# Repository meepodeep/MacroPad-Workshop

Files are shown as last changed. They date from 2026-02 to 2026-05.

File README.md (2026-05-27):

# MacroPad-Workshop
macro pad design for the CFMG workshop
# ASSEMBLY STEPS

1. bend the legs of the diodes and put them into the holes labeled d(x) on the back of the pcb (the side with the logo). make sure the black stripe on the diode is pointing to the square hole
2. solder them in from the side where they are sticking out
3. cut the legs off the diodes
4. click the switches into the plate with the pins facing up
5. solder the pin headers that were included with the microcontroller on the back side of the board (side with logo), the short side of the headers go through the pcb.
6. click the switches and plate onto the board and then solder the switches.
7. solder the microcontroller onto the pin headers one pin above the bottom, this is due to an error in the library i used.

# FLASHING STEPS

1. install qmk toolbox
2. install the cmfg_macropad_default.hex file from this repo
3. select it in qmk toolbox
4. select auto flash
5. connect the macropad to your computer and then short the reset and ground pins using some metal thing

# BOM

|Item |Price|Quantity|Use |Link |
|---|-----|---|---|---|
|Switches |5.81 |30pcs |switches |https://www.aliexpress.us/item/3256811859979458.html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 |
|Pro micro |4.38 |1 |runs the macropad|https://www.aliexpress.us/item/2251801390587459.html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 |
|1N4148 Diode|2.68 |1 |is diode |https://www.aliexpress.us/item/3256804886900665.html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|
|Keycaps |4.07 |1 |is keycap |https://www.aliexpress.us/item/3256808845306164.html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 |

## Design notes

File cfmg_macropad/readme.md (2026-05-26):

# cfmg_macropad

cfmg_macropad

*A short description of the keyboard/project*

* Keyboard Maintainer: [meepodeep](https://github.com/meepodeep)
* Hardware Supported: *The PCBs, controllers supported*
* Hardware Availability: *Links to where you can find this hardware*

Make example for this keyboard (after setting up your build environment):

    make cfmg_macropad:default

Flashing example for this keyboard:

    make cfmg_macropad:default:flash

See the [build environment setup](https://docs.qmk.fm/#/getting_started_build_tools) and the [make instructions](https://docs.qmk.fm/#/getting_started_make_guide) for more information. Brand new to QMK? Start with our [Complete Newbs Guide](https://docs.qmk.fm/#/newbs).

## Bootloader

Enter the bootloader in 3 ways:

* **Bootmagic reset**: Hold down the key at (0,0) in the matrix (usually the top left key or Escape) and plug in the keyboard
* **Physical reset button**: Briefly press the button on the back of the PCB - some may have pads you must short instead
* **Keycode in layout**: Press the key mapped to `QK_BOOT` if it is available

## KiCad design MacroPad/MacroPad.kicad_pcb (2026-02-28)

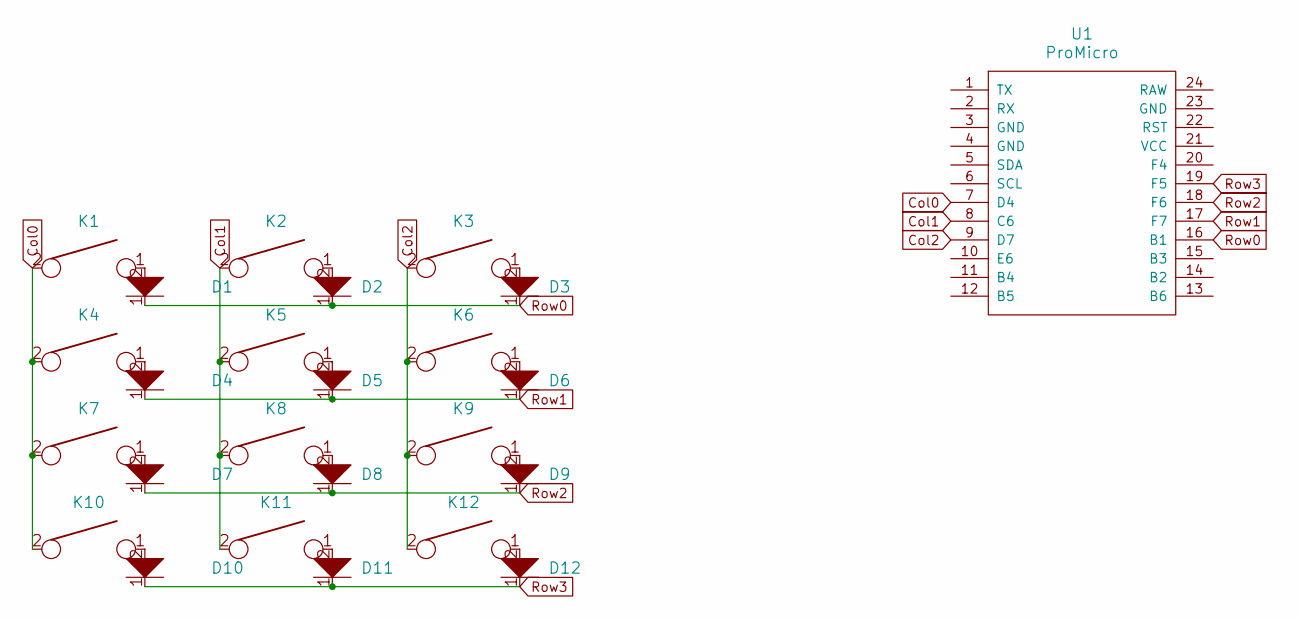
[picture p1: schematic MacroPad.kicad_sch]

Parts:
D1, D2, D3, D4, D5, D6, D7, D8, D9, D10, D11, D12: D; D_SOD123_axial
K1, K2, K3, K4, K5, K6, K7, K8, K9, K10, K11, K12: KEYSW; Mx_Alps_100
U1: ProMicro; Pro_Micro

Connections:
Col0: K1.2, K4.2, K7.2, K10.2, U1.7 (D4)
Col1: K2.2, K5.2, K8.2, K11.2, U1.8 (C6)
Col2: K3.2, K6.2, K9.2, K12.2, U1.9 (D7)
unnamed: D1.2, K1.1
unnamed: D2.2, K2.1
unnamed: D3.2, K3.1
unnamed: D4.2, K4.1
unnamed: D5.2, K5.1
unnamed: D6.2, K6.1
unnamed: D7.2, K7.1
unnamed: D8.2, K8.1
unnamed: D9.2, K9.1
unnamed: D10.2, K10.1
unnamed: D11.2, K11.1
unnamed: D12.2, K12.1
Row0: D1.1, D2.1, D3.1, U1.16 (B1)
Row1: D4.1, D5.1, D6.1, U1.17 (F7)
Row2: D7.1, D8.1, D9.1, U1.18 (F6)
Row3: D10.1, D11.1, D12.1, U1.19 (F5)

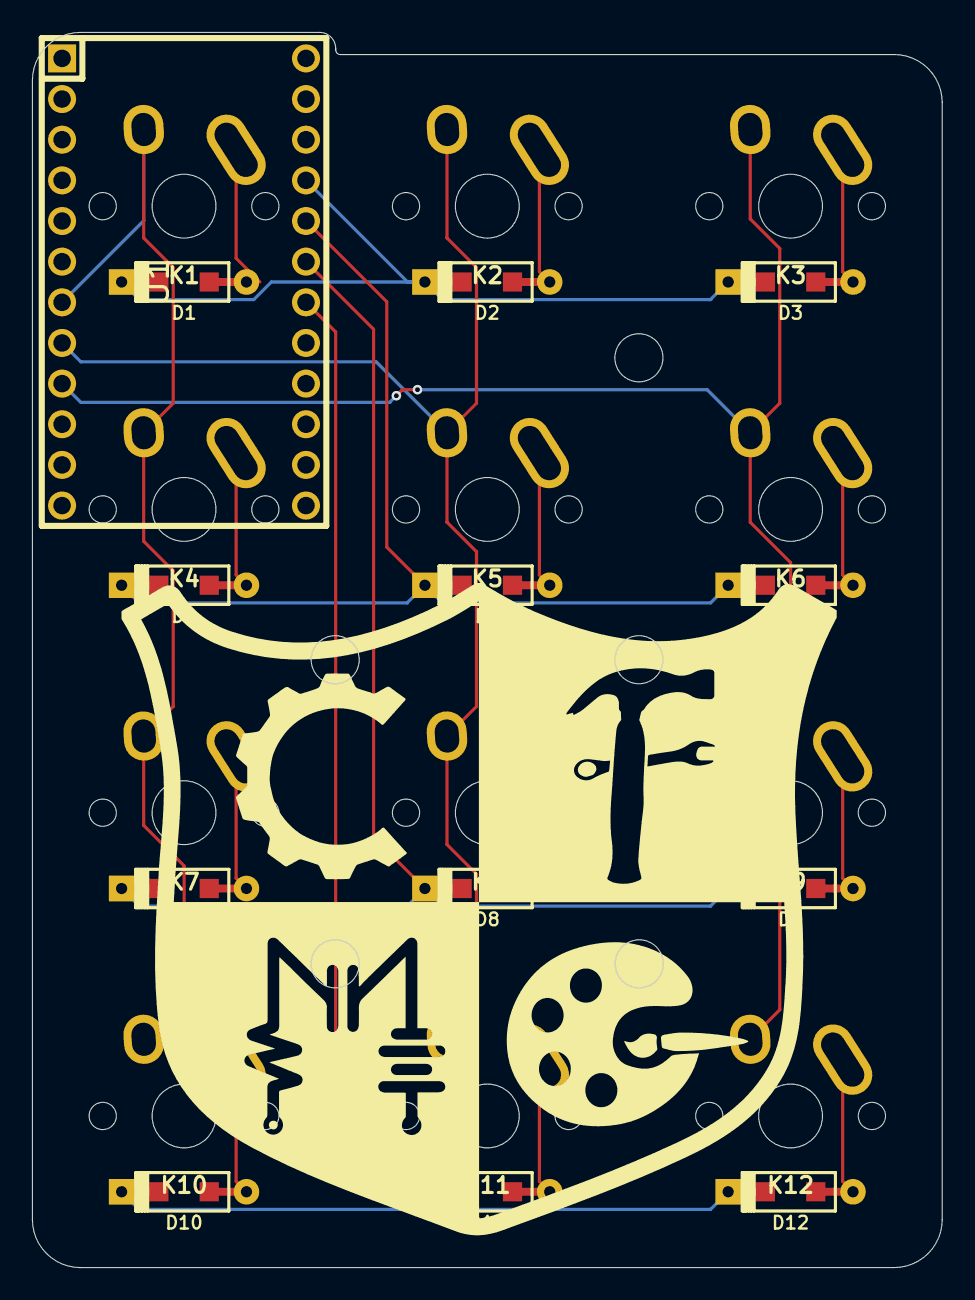
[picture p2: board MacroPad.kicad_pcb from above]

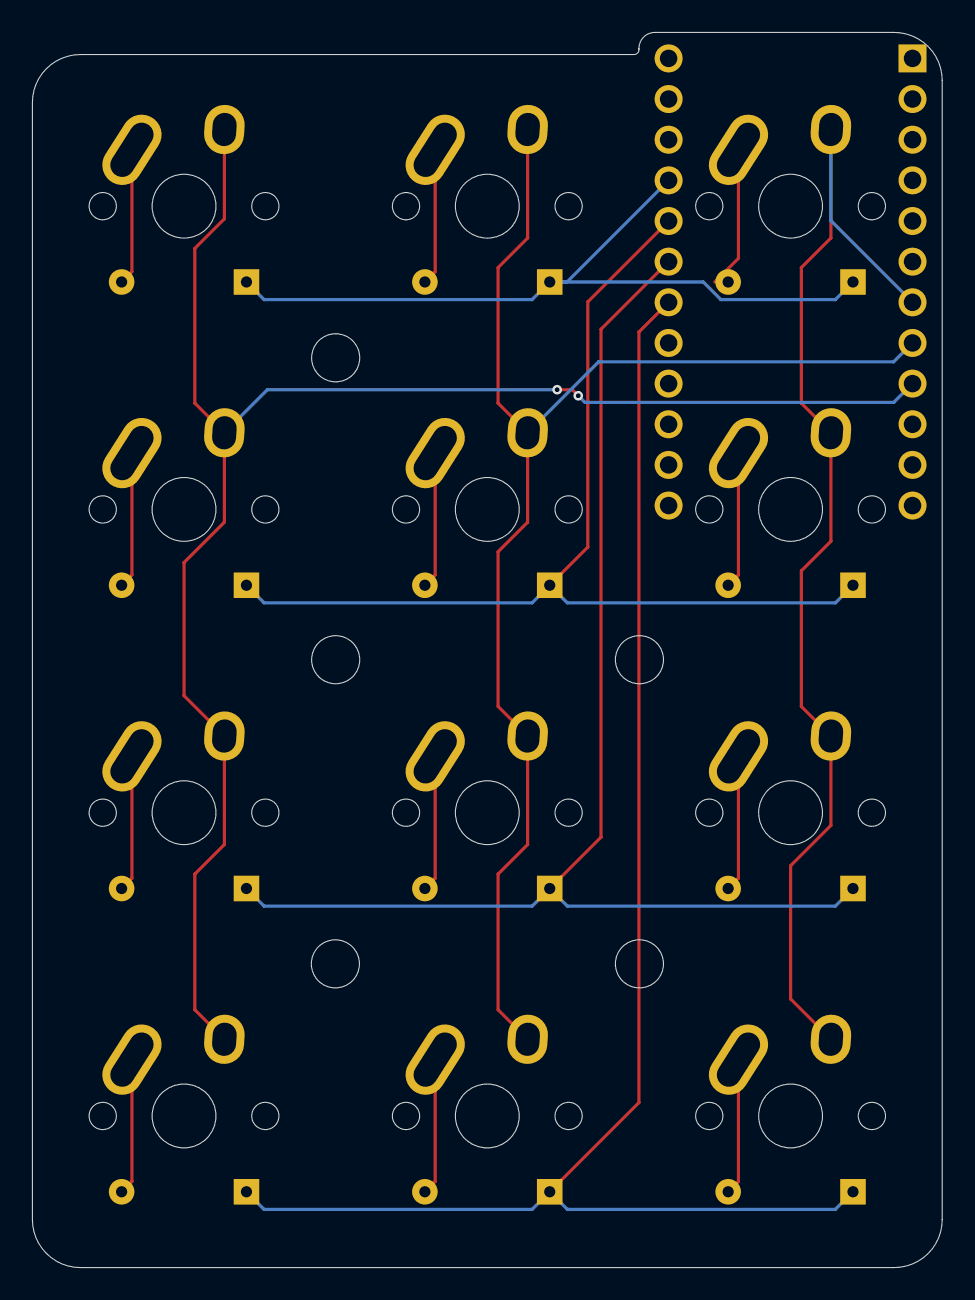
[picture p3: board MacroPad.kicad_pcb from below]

Board: 2 copper layers, 56.8 x 77.2 mm, 25 parts (12 on the bottom side), 19 nets.
